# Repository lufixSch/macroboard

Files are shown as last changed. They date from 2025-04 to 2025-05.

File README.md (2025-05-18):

# Macroboard

DIY Macro keyboard with pedal support based on Arduino Micro.

This project contains the build files and firmware for an plug and play macro keyboard. It doesn't require any third party software on your PC instead it makes use of the **F13** - **F24** keys which are usually unused. The (optional) mode switch allows a secondary layer of macro keys (**F1** - **F12**).
In addition the board has a port for a sustain pedal from a E-Piano with automatic polarity detection. The design includes a separate mode switch for the pedal as well as a manual polarity switch to allow more exceptional use cases like push to mute in games where only push to talk is supported.

## Circuit

Contains the PCB design for the board based around an Arduino Micro development board.

Not all switches/keys need to be populated. You can omit _Special Key_, _Mode Switch_ and _Special Switch 1/2_ based on your needs and disable the corresponding features in the firmware.

## Firmware

Contains the Arduino sketch which should be flashed onto the Arduino Micro. The firmware relies on the Arduino Keyboard library and can be configured using macros in the `settings.h`.

## Case

Contains the FreeCAD as well as STL files for a simple printable enclosure for the _Macroboard_.

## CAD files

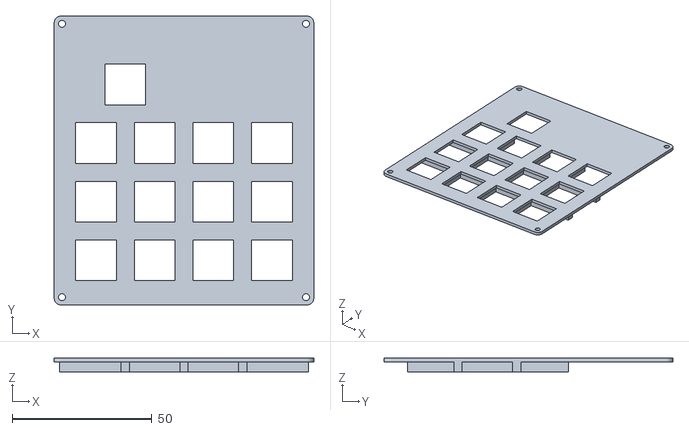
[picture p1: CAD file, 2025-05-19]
case/case-top.stl
93.0 x 103.5 x 4.90

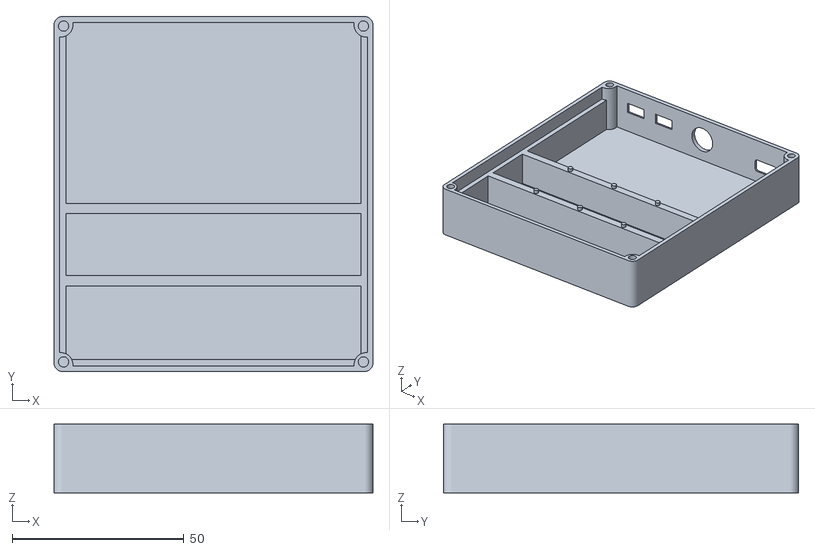
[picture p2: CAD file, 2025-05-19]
case/case-bottom.stl
93.0 x 103.5 x 20.0

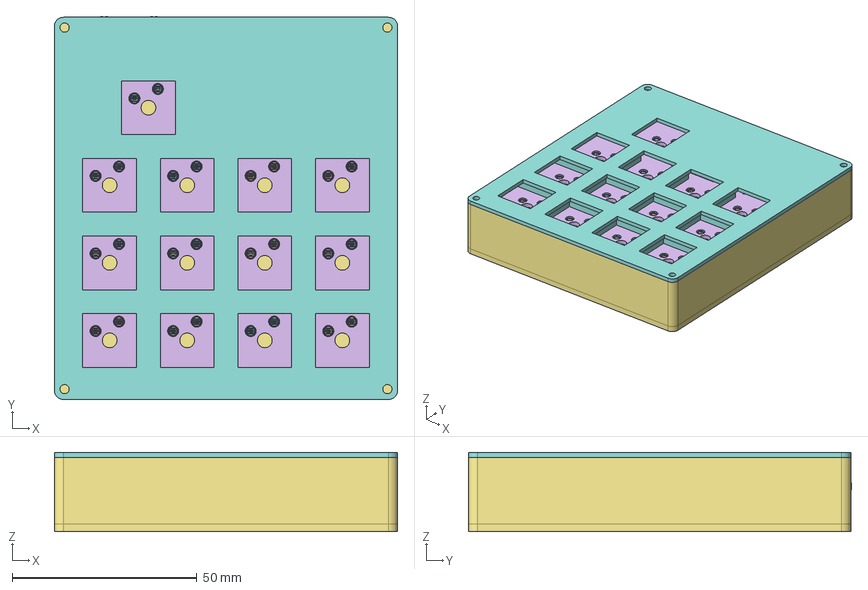
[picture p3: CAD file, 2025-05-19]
case/case.FCStd
93.0 x 103.7 x 21.4 mm
KailhSocket
KailhSocket001
KailhSocket002
KailhSocket004
KailhSocket005
KailhSocket006
KailhSocket008
KailhSocket009
KailhSocket010
KailhSocket012
KailhSocket013
KailhSocket014
KailhSocket016
KailhSocket017
KailhSocket018
KailhSocket020
KailhSocket021
KailhSocket022
KailhSocket024
KailhSocket025
KailhSocket026
KailhSocket028
KailhSocket029
KailhSocket030
KailhSocket032
KailhSocket033
KailhSocket034
KailhSocket036
KailhSocket037
KailhSocket038
KailhSocket040
KailhSocket041
KailhSocket042
KailhSocket044
KailhSocket045
KailhSocket046
KailhSocket048
KailhSocket049
KailhSocket050
C_0805_2012Metric
R_0805_2012Metric
R_0805_2012Metric001
R_0805_2012Metric002
PinHeader_1x12_P2.54mm_Vertical
PinHeader_1x12_P2.54mm_Vertical001
C_0805_2012Metric001
R_0805_2012Metric003
R_0805_2012Metric004
R_0805_2012Metric005
R_0805_2012Metric006
R_0805_2012Metric007
R_0805_2012Metric008
R_0805_2012Metric009
R_0805_2012Metric010
C_0805_2012Metric002
R_0805_2012Metric011
C_0805_2012Metric003
C_0805_2012Metric004
R_0805_2012Metric012
C_0805_2012Metric005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

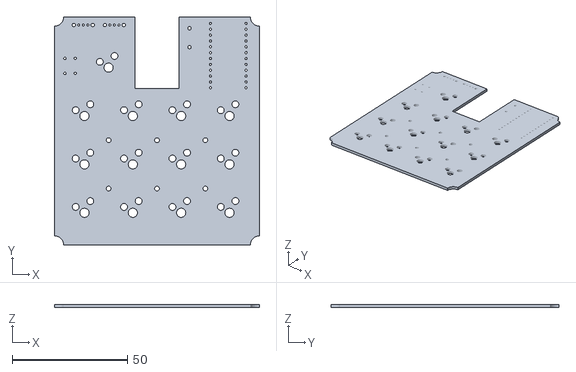
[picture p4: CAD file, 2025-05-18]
case/pcb-body.stl
89.0 x 99.0 x 1.51

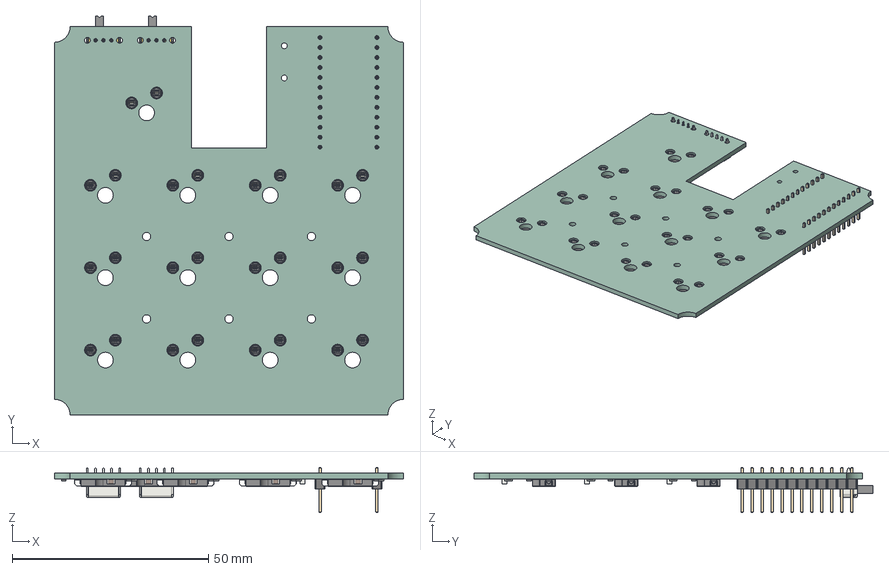
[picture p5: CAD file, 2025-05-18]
case/pcb.step
89.0 x 101.7 x 11.5 mm
KailhSocket x 13
C_0805_2012Metric x 16
R_0805_2012Metric x 32
PinHeader_1x12_P2.54mm_Vertical x 2
SW_Slide_SPDT_Angled_CK_OS102011MA1Q x 2
macroboard_PCB

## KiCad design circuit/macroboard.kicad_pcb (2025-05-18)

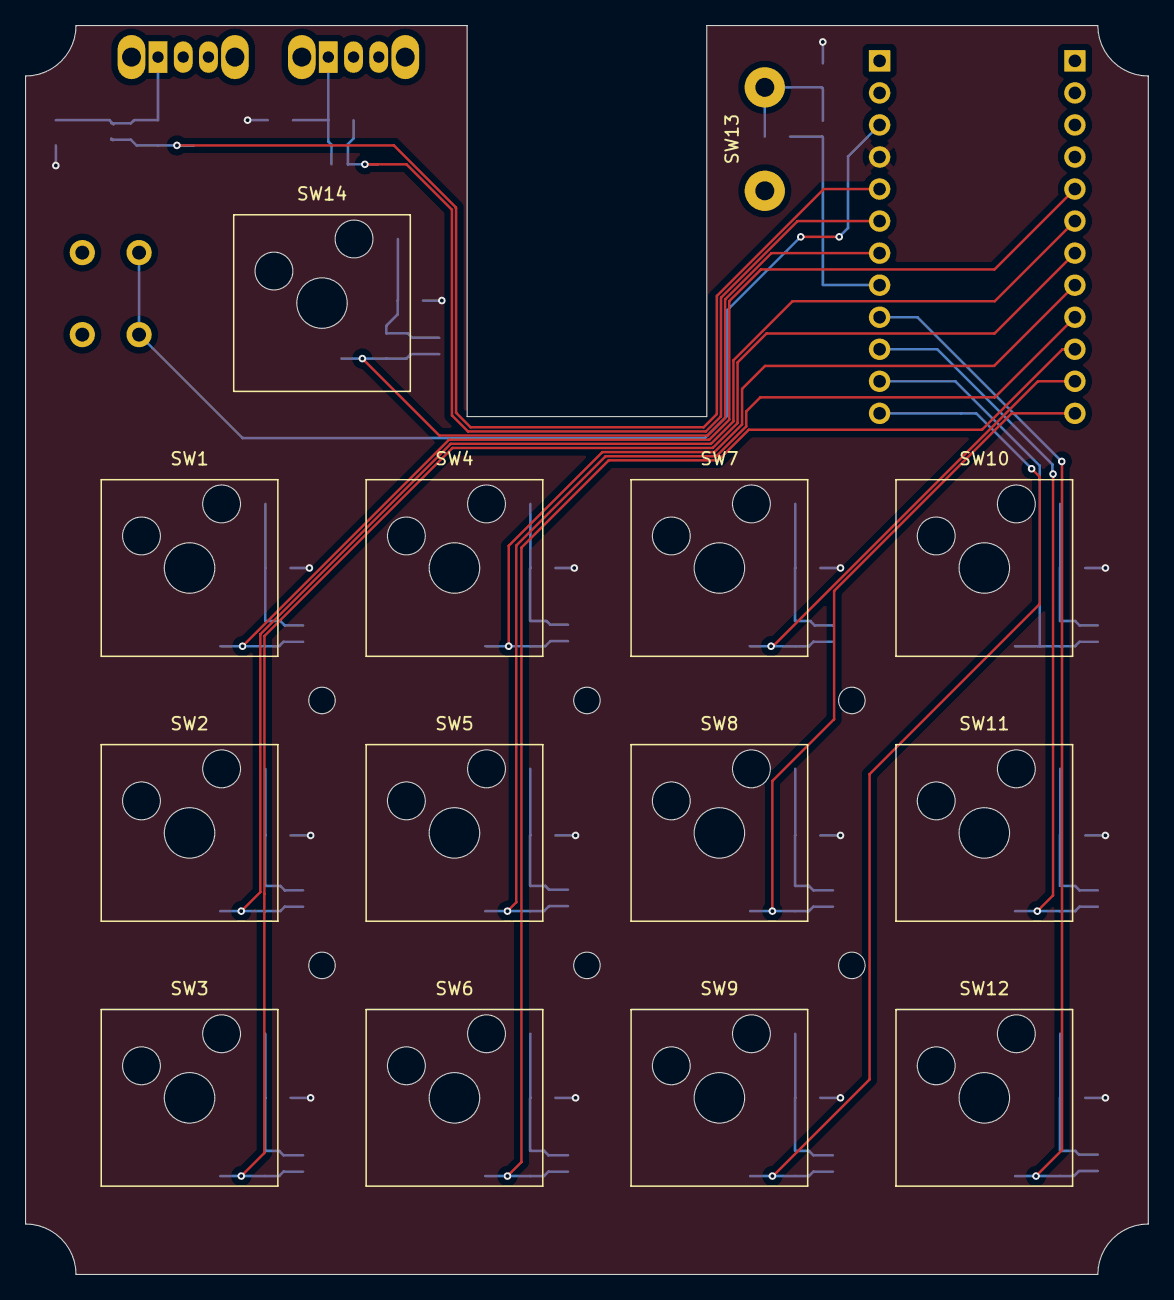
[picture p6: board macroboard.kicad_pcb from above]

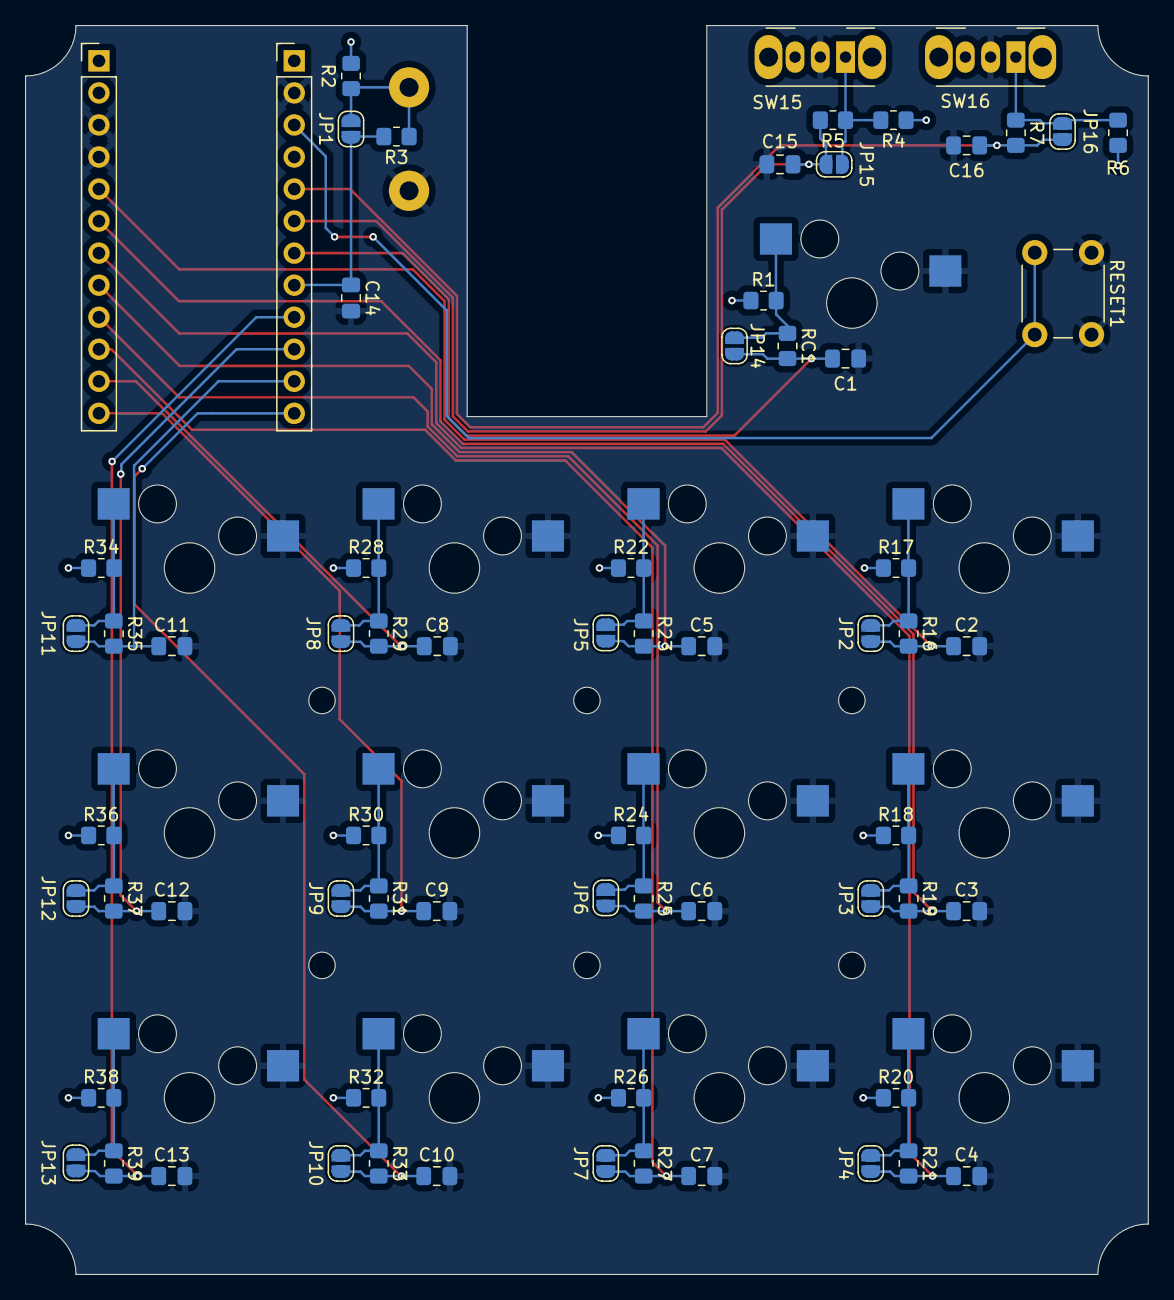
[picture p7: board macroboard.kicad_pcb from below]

Board: 2 copper layers, 89.0 x 99.0 mm, 88 parts (68 on the bottom side), 35 nets.

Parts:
C1, C2, C3, C4, C5, C6, C7, C8, C9, C10, C11, C12, C13, C14, C15, C16: 10u; C_0805_2012Metric_Pad1.18x1.45mm_HandSolder
H1, H2, H3, H4, H5, H6: MountingHole; MountingHole_2.1mm
JP1, JP2, JP3, JP4, JP5, JP6, JP7, JP8, JP9, JP10, JP11, JP12, JP13, JP14, JP15, JP16: Jumper_2_Open; SolderJumper-2_P1.3mm_Open_RoundedPad1.0x1.5mm
R1, R2, R4, R6, R17, R18, R20, R22, R24, R26, R28, R30, R32, R34, R36, R38: 10k; R_0805_2012Metric_Pad1.20x1.40mm_HandSolder
R3, R5, R7, R16, R19, R21, R23, R25, R27, R29, R31, R33, R35, R37, R39: 1k; R_0805_2012Metric_Pad1.20x1.40mm_HandSolder
RC1: 1k; R_0805_2012Metric_Pad1.20x1.40mm_HandSolder
RESET1: SW_Push; SW_PUSH_6mm
SW1, SW2, SW3, SW4, SW5, SW6, SW7, SW8, SW9, SW10, SW11, SW12, SW14: CherryMX; CherryMX_1.00u_KailhSocket
SW13: SW_Push; AUX Jack 6.3mm External
SW15, SW16: SW_SPDT; SW_Slide_SPDT_Angled_CK_OS102011MA1Q
U1: ATmega32U4-A; Arduino Pro Micro

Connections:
/Debounce13/IN: JP1.1 (A), R2.2, R3.1, SW13.2
/Debounce15/IN: JP15.1 (A), R4.2, R5.1, SW15.1 (A)
/Debounce16/IN: JP16.1 (A), R6.2, R7.1, SW16.1 (A)
/KEY1: C2.1, JP2.2 (B), R16.2, U1.19 (PD1)
/KEY2: C3.1, JP3.2 (B), R19.2, U1.18 (PD0)
/KEY3: C4.1, JP4.2 (B), R21.2, U1.25 (PD4)
/KEY4: C5.1, JP5.2 (B), R23.2, U1.31 (PC6)
/KEY5: C6.1, JP6.2 (B), R25.2, U1.27 (PD7)
/KEY6: C7.1, JP7.2 (B), R27.2, U1.1 (PE6)
/KEY7: C8.1, JP8.2 (B), R29.2, U1.28 (PB4)
/KEY8: C9.1, JP9.2 (B), R31.2, U1.29 (PB5)
/KEY9: C10.1, JP10.2 (B), R33.2, U1.30 (PB6)
/KEY10: C11.1, JP11.2 (B), R35.2, U1.10 (PB2)
/KEY11: C12.1, JP12.2 (B), R37.2, U1.11 (PB3)
/KEY12: C13.1, JP13.2 (B), R39.2, U1.9 (PB1)
/MODE_SWITCH: C1.1, JP14.2 (B), RC1.2, U1.37 (PF6)
/SPECIAL_KEY: C14.1, JP1.2 (B), R3.2, U1.36 (PF7)
/SPECIAL_SWITCH_1: C15.1, JP15.2 (B), R5.2, U1.38 (PF5)
/SPECIAL_SWITCH_2: C16.1, JP16.2 (B), R7.2, U1.39 (PF4)
/Switch1/Debounce1/IN: JP2.1 (A), R16.1, R17.2, SW1.2
/Switch2/Debounce1/IN: JP3.1 (A), R18.2, R19.1, SW2.2
/Switch3/Debounce1/IN: JP4.1 (A), R20.2, R21.1, SW3.2
/Switch4/Debounce1/IN: JP5.1 (A), R22.2, R23.1, SW4.2
/Switch5/Debounce1/IN: JP6.1 (A), R24.2, R25.1, SW5.2
/Switch6/Debounce1/IN: JP7.1 (A), R26.2, R27.1, SW6.2
/Switch7/Debounce1/IN: JP8.1 (A), R28.2, R29.1, SW7.2
/Switch8/Debounce1/IN: JP9.1 (A), R30.2, R31.1, SW8.2
/Switch9/Debounce1/IN: JP10.1 (A), R32.2, R33.1, SW9.2
/Switch10/Debounce1/IN: JP11.1 (A), R34.2, R35.1, SW10.2
/Switch11/Debounce1/IN: JP12.1 (A), R36.2, R37.1, SW11.2
/Switch12/Debounce1/IN: JP13.1 (A), R38.2, R39.1, SW12.2
/Switch13/Debounce1/IN: JP14.1 (A), R1.2, RC1.1, SW14.2
GND: C1.2, C2.2, C3.2, C4.2, C5.2, C6.2, C7.2, C8.2, C9.2, C10.2, C11.2, C12.2, C13.2, C14.2, C15.2, C16.2, RESET1.1, SW1.1, SW2.1, SW3.1, SW4.1, SW5.1, SW6.1, SW7.1, SW8.1, SW9.1, SW10.1, SW11.1, SW12.1, SW13.1, SW14.1, SW15.2 (B), SW16.2 (B), U1.5 (UGND), U1.15 (GND)
unnamed: RESET1.2, U1.13 (~RESET)
VCC: R1.1, R2.1, R4.1, R6.1, R17.1, R18.1, R20.1, R22.1, R24.1, R26.1, R28.1, R30.1, R32.1, R34.1, R36.1, R38.1, U1.14 (VCC)

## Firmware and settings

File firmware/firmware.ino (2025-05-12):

#include <Keyboard.h>

#include "gpio.h"
#include "settings.h"

// Variable to keep track of the current macro mode
int macro_mode = 0;

// Array to store the previous state of each key
bool prev_key_states[MACRO_KEY_CNT];

#ifdef HAS_SPECIAL_KEY

bool prev_special_key_state;

int special_key_polarity = 0;
int special_key_polarity_mode = 0;
int special_key_mode = 0;

#endif


#ifdef HAS_MODE_SWITCH

// Variable to track if the mode switch is currently pressed
bool mode_switch_is_pressed = false;

#endif


// Setup function to initialize pins and start keyboard communication
void setup() {
  delay(100); // Ensure stable states

  // Set each macro key pin as an input with a pull-up resistor
  for (int pin = 0; pin < MACRO_KEY_CNT; pin++) {
    pinMode(MACRO_KEY_PINS[pin], INPUT_PULLUP);
    prev_key_states[pin] = digitalRead(MACRO_KEY_PINS[pin]); // Initialize previous states
  }

#ifdef HAS_SPECIAL_KEY

  // Set the special key pin as an input with a pull-up resistor
  pinMode(SPECIAL_KEY_PIN, INPUT_PULLUP);
  prev_special_key_state = digitalRead(SPECIAL_KEY_PIN);

  special_key_polarity = SPECIAL_KEY_POLARITY >= 0 ? SPECIAL_KEY_POLARITY : prev_special_key_state;

  pinMode(SPECIAL_KEY_POLARITY_SWITCH_PIN, INPUT_PULLUP);
  special_key_polarity_mode = !digitalRead(SPECIAL_KEY_POLARITY_SWITCH_PIN);

  pinMode(SPECIAL_KEY_MODE_SWITCH_PIN, INPUT_PULLUP);
  special_key_mode = !digitalRead(SPECIAL_KEY_MODE_SWITCH_PIN);
#endif


#ifdef HAS_MODE_SWITCH

  // Set the mode switch pin as an input with a pull-up resistor
  pinMode(MODE_SWITCH_PIN, INPUT_PULLUP);

#endif

  // Start keyboard communication
  Keyboard.begin();
}

// Detect rising edge and press corresponding key
void pressKey(bool prev_state, bool curr_state, int key) {
  if (curr_state && !prev_state) {
    // Key was pressed
    Keyboard.press(key);
    // Serial.print("Press: ");
    // Serial.println(key);
  } else if (!curr_state && prev_state) {
    // Key was released
    Keyboard.release(key);
    // Serial.print("Release: ");
    // Serial.println(key);
  }
}



// Main loop to handle key presses and macro modes
void loop() {
  // Select the appropriate key mapping based on the current macro mode
  const int *key_map =
      macro_mode == 0 ? MACRO_KEY_MAP : MACRO_KEY_MAP_ALT;

  // Check each macro key for a press or release
  for (int pin = 0; pin < MACRO_KEY_CNT; pin++) {
    bool current_state = digitalRead(MACRO_KEY_PINS[pin]);

    pressKey(!prev_key_states[pin], !current_state, key_map[pin]);

    // Update the previous state of the key
    prev_key_states[pin] = current_state;
  }

#ifdef HAS_SPECIAL_KEY

  special_key_polarity_mode = !digitalRead(SPECIAL_KEY_POLARITY_SWITCH_PIN);
  special_key_mode = !digitalRead(SPECIAL_KEY_MODE_SWITCH_PIN);

  bool current_state = digitalRead(SPECIAL_KEY_PIN);
  bool polarity = special_key_polarity ^ special_key_polarity_mode;

  pressKey(
    prev_special_key_state ^ polarity, 
    current_state ^ polarity, 
    special_key_mode == 0 ? SPECIAL_KEY : SPECIAL_KEY_ALT
  );

  // Update the previous state of the key
  prev_special_key_state = current_state;

#endif

#ifdef HAS_MODE_SWITCH

  // Check if the mode switch is pressed
  if (!digitalRead(MODE_SWITCH_PIN)) {
    if (mode_switch_is_pressed == false) {
      // Toggle the macro mode if the switch is not already considered pressed
      macro_mode = !macro_mode;
      // Mark the mode switch as pressed
      mode_switch_is_pressed = true;
    }
  } else {
    // Reset the mode switch press state when it is released
    mode_switch_is_pressed = false;
  }

#endif

  delay(10); // Small delay to debounce the keys
}

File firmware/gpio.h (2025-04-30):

#ifndef GPIO_H
#define GPIO_H

#define PIN_2 2
#define PIN_3 3
#define PIN_4 4
#define PIN_5 5
#define PIN_6 6
#define PIN_7 7
#define PIN_8 8
#define PIN_9 9
#define PIN_10 10

#define PIN_14 14
#define PIN_15 15
#define PIN_16 16

#endif

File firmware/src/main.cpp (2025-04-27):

#include <Arduino.h>
#include <Keyboard.h>

// Define whether the special key is present
#define HAS_SPECIAL_KEY
// Define wether mode switch functionality is present
#define HAS_MODE_SWITCH

// Variable to keep track of the current macro mode
int macro_mode = 0;

#ifdef HAS_SPECIAL_KEY

// Pin and key mapping for the special key
#define SPECIAL_KEY_PIN PORTF7
#define SPECIAL_KEY_MAP KEY_F12

// Number of macro keys and their pin mappings
#define MACRO_KEY_CNT 13
const int MACRO_KEY_PINS[] = {PORTD1, PORTD0, PORTD4,         PORTC6, PORTD7,
                              PORTE6, PORTB4, PORTB5,         PORTB6, PORTB2,
                              PORTB3, PORTB1, SPECIAL_KEY_PIN};
// Key mappings for the macro keys in primary mode
const int MACRO_KEY_MAP[] = {KEY_F13, KEY_F14, KEY_F15,        KEY_F16, KEY_F17,
                             KEY_F18, KEY_F19, KEY_F20,        KEY_F21, KEY_F22,
                             KEY_F23, KEY_F24, SPECIAL_KEY_MAP};

// Key mappings for the macro keys in secondary mode
const int MACRO_KEY_MAP_SECONDARY[] = {
    KEY_F1, KEY_F2, KEY_F3,  KEY_F4,  KEY_F5,  KEY_F6,         KEY_F7,
    KEY_F8, KEY_F9, KEY_F10, KEY_F11, KEY_F12, SPECIAL_KEY_MAP};

#else

// Number of macro keys and their pin mappings without the special key
#define MACRO_KEY_CNT 12
const int MACRO_KEY_PINS[] = {PORTD1, PORTD0, PORTD4, PORTC6, PORTD7, PORTE6,
                              PORTB4, PORTB5, PORTB6, PORTB2, PORTB3, PORTB1};
// Key mappings for the macro keys in primary mode without the special key
const int MACRO_KEY_MAP[] = {KEY_F13, KEY_F14, KEY_F15, KEY_F16,
                             KEY_F17, KEY_F18, KEY_F19, KEY_F20,
                             KEY_F21, KEY_F22, KEY_F23, KEY_F24};

// Key mappings for the macro keys in secondary mode without the special key
const int MACRO_KEY_MAP_SECONDARY[] = {KEY_F1, KEY_F2,  KEY_F3,  KEY_F4,
                                       KEY_F5, KEY_F6,  KEY_F7,  KEY_F8,
                                       KEY_F9, KEY_F10, KEY_F11, KEY_F12};

#endif

#ifdef HAS_MODE_SWITCH

// Pin for the mode switch
#define MODE_SWITCH_PIN PORTF6

// Variable to track if the mode switch is currently pressed
bool mode_switch_is_pressed = false;

#endif

// Setup function to initialize pins and start keyboard communication
void setup() {
  // Set each macro key pin as an input with a pull-up resistor
  for (int pin = 0; pin < MACRO_KEY_CNT; pin++) {
    pinMode(MACRO_KEY_PINS[pin], INPUT_PULLUP);
  }

#ifdef HAS_MODE_SWITCH

  // Set the mode switch pin as an input with a pull-up resistor
  pinMode(MODE_SWITCH_PIN, INPUT_PULLUP);

#endif

  // Start keyboard communication
  Keyboard.begin();
}

// Main loop to handle key presses and macro modes
void loop() {
  // Select the appropriate key mapping based on the current macro mode
  const int *key_map =
      macro_mode == 0 ? MACRO_KEY_MAP : MACRO_KEY_MAP_SECONDARY;

  // Check each macro key for a press or release
  for (int pin = 0; pin < MACRO_KEY_CNT; pin++) {
    if (!digitalRead(MACRO_KEY_PINS[pin])) {
      // Release the key if it is not pressed
      Keyboard.release(key_map[pin]);
    } else {
      // Press the key if it is pressed
      Keyboard.press(key_map[pin]);
    }
  }

#ifdef HAS_MODE_SWITCH

  // Check if the mode switch is pressed
  if (!digitalRead(MODE_SWITCH_PIN)) {
    if (mode_switch_is_pressed == false) {
      // Toggle the macro mode if the switch is not already considered pressed
      macro_mode = !macro_mode;
      // Mark the mode switch as pressed
      mode_switch_is_pressed = true;
    }
  } else {
    // Reset the mode switch press state when it is released
    mode_switch_is_pressed = false;
  }

#endif
}

// Main function to start the setup and loop functions
int main() {
  setup();

  while (true) {
    loop();
  }
}

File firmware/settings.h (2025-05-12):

#ifndef SETTINGS_H
#define SETTINGS_H

#include <Keyboard.h>

// Define whether the special key is present
#define HAS_SPECIAL_KEY
#define SPECIAL_KEY_POLARITY -1 // -1 AUTO, 0 = NO, 1 = NC

#define SPECIAL_KEY_POLARITY_SWITCH_PIN PIN_A3
#define SPECIAL_KEY_MODE_SWITCH_PIN PIN_A2

// Define whether mode switch functionality is present
// #define HAS_MODE_SWITCH
// #define MODE_SWITCH_PIN PF6

// Keyboard Configuration
#define MACRO_KEY_CNT 12 // Number of macro keys without the special key
const int MACRO_KEY_PINS[] = {PIN_2, PIN_3, PIN_4,  PIN_5,  PIN_6,  PIN_7,
                              PIN_8, PIN_9, PIN_10, PIN_16, PIN_14, PIN_15};

#define SPECIAL_KEY_PIN PIN_A0

// Key Mappings
const int MACRO_KEY_MAP[] = {KEY_F13, KEY_F14, KEY_F15, KEY_F16,
                             KEY_F17, KEY_F18, KEY_F19, KEY_F20,
                             KEY_F21, KEY_F22, KEY_F23, KEY_F24};

#define SPECIAL_KEY KEY_F12

// Alt Key Mappings (Only used if mode switching is enabled)
const int MACRO_KEY_MAP_ALT[] = {KEY_F1, KEY_F2,  KEY_F3,  KEY_F4,
                                 KEY_F5, KEY_F6,  KEY_F7,  KEY_F8,
                                 KEY_F9, KEY_F10, KEY_F11, KEY_F12};

#define SPECIAL_KEY_ALT KEY_ESC

#endif

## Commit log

2025-04-27 add circuit design
    [macroboard.kicad_pcb, macroboard.kicad_sch]
2025-04-27 add cherry mx lib submodule, add basic circuit
    [macroboard.kicad_sch]
2025-04-27 add basic pcb layout (no routing)
    [macroboard.kicad_pcb, macroboard.kicad_sch]
2025-04-30 move firmware to Arduino Sketch (Issue with PIO), fix minor issues
    [firmware.ino]
2025-04-30 add reusable debounce circuit with solder jumper
    [macroboard.kicad_pcb, macroboard.kicad_sch, switch.kicad_sch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]
2025-04-30 add custom footprints, improve layout
    [macroboard.kicad_pcb, macroboard.kicad_sch, switch.kicad_sch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]
2025-05-03 add special switches, add routing
    [macroboard.kicad_pcb, macroboard.kicad_sch, switch_debounce.kicad_sch]
2025-05-05 add reset switch
    [macroboard.kicad_pcb, macroboard.kicad_sch]
2025-05-05 add gerber files
    [macroboard-B_Cu.gbr, macroboard-B_Mask.gbr, macroboard-B_Paste.gbr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]
2025-05-12 add special key mode and polarity switch, add special key auto polarity
2025-05-12 fix wrong pin distance on Arduino micro footprint
    [macroboard.kicad_pcb, macroboard.kicad_sch]
2025-05-18 add case
    [case-bottom.stl, case-top.stl, case.FCStd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]
2025-05-18 improve switch positioning
    [macroboard.kicad_pcb]
2025-05-19 improve case stability and printability
    [case-bottom.stl, case-top.stl, case.FCStd]
